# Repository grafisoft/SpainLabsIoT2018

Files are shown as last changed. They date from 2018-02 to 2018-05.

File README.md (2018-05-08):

Banner

Banner

# SpainLabsIoT2018
Hardware&Firmware creado para el mini curso IoT basado en ESP8266

En este repositorio se pretende subir todos los archivos correspondientes al hardware y firmware creados para el 
curso de IoT SpainLabsIoT2018. Podemos acceder a los contenidos desde el enlace: https://www.spainlabs.com/foros/tema-SpainLabs-con-el-IoT-para-tod-s

El hardware lo podemos ver mas en detalle en: https://www.spainlabs.com/foros/tema-SpainLabsIoT2018-Caso-real-Nodos-ESP8266

El hardware esta basado en la integración del módulo de comunicaciones wifi ESP8266 en sus especificaciones 07/12/12E.

El proyecto del firmware que se ofrece esta escrito usando el IDE de Atom+ Proyecto PlatformIO: https://platformio.org/

Este proyecto forma parte de la comunidad maker spainlabs.com y mas concretamente al usuario Grafisoft.

Podeis hacer uso de todo el contenido sin restricciones siempre y cuando se indique que pertenece a Grafisoft de spainlabs.com

Características:

- Placa desarrollada para ESP8266-07/12/12E.
-Dimensiones: 78mm x 41mm.
- Módulo ESP extraible o posibilidad de soldar directamente sobre la PCB.
- Etapa de carga para las baterías Lipo. Ya sea mediante panel solar (6V-1W) o mediante una conexión de 5V externa.
- Todos los pines del ESP son accesibles. También lo son los de alimentación (tanto Vbat como Vext).
- Programación del ESP desde la propia placa mediante un conversión USB-Serie (este conversor debe ser un modelo que tenga ciertos pines accesibles).
- Bajo consumo en DeepSleep: <50uA.
- Conexión de una batería mediante conector JST o compatible con un holder para baterías de 1 o 2 celdas tipo 18650.
- Botón de reset.
- Nivel de batería: Podremos consultar el nivel de nuestras baterías para conocer su estado.
- Modular: Esto es, no es necesario tener soldadas todas las etapas para su funcionamiento. De cara a desplegar una red, no tenemos porque soldar todos los componentes para tener un nodo operativo. Por lo que tenemos un cierto ahorro en el momento de desplegar nodos.
- Se dispone de zócalos para poder pinchar una placa encima de forma que en ella podamos integrar la electrónica necesaria para añadir mas sensores.
- Se ha dejado huella para zócalo 2x2 y disponer unicamente acceso a I2C y alimentación 3v3.
- Su coste en componentes ronda los 6€ sin incluir el módulo ESP ni batería(s). Es un coste bastante razonable.

Desarrollo de una shield para conectar sensores: https://github.com/grafisoft/Smart-Sensors-Shield

-------------------------------------------------

ESp8266 IoT Board for SpainLabsIoT2018 course is based on ESP8266 NodeMCU. Some changes are do and new version is created. We can use the board as if we were using NodeMCU or any ESP8266 module.

Features:

- Board developed for ESP8266-07/12/12E version modules.
- Dimensions: 78mm x 41mm.
- Designed to use non-fixed modules or you can soldier it.
- Include battery Lipo charger. We can use a solar panel (6V-1W) or external power-dc 5v.
- All ESP8266 module pins are accessible. Power pins accessible too (Vbat and Vext).
- ESP8266 can be programmed using external USB-Serial: https://www.ebay.es/itm/USB-2-0-to-TTL-UART-6PIN-CP2102-Module-Serial-Converter-T1/252583963023?rmvSB=true 
- Low power DeepSleep current: 50uA. *Note: We need extract resistor betwen leds components.
- Battery connector is JST type or we can use a battery holder (1 or 2 cells). Battery type is 18650.
- Reset button.
- Battery level: ADC of ESP module is used to measure battery level.
- It is not necessary to weld all the components. Board can work with parcial smd components. We can get low cost when we need to deploy some nodes and weld necessary components only. 
- Board provide some connectors to add personal shields and increase board features or integrate new sensors.
- Board include footprint for I2C connector. Shape is 2x2.
- Board costs are over 6€. Not included ESP module or battery.

I am developing a shield for sensors: https://github.com/grafisoft/Smart-Sensors-Shield

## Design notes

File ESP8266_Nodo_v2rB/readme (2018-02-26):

Gerbers para enviar a fabricar el modelo de placa.

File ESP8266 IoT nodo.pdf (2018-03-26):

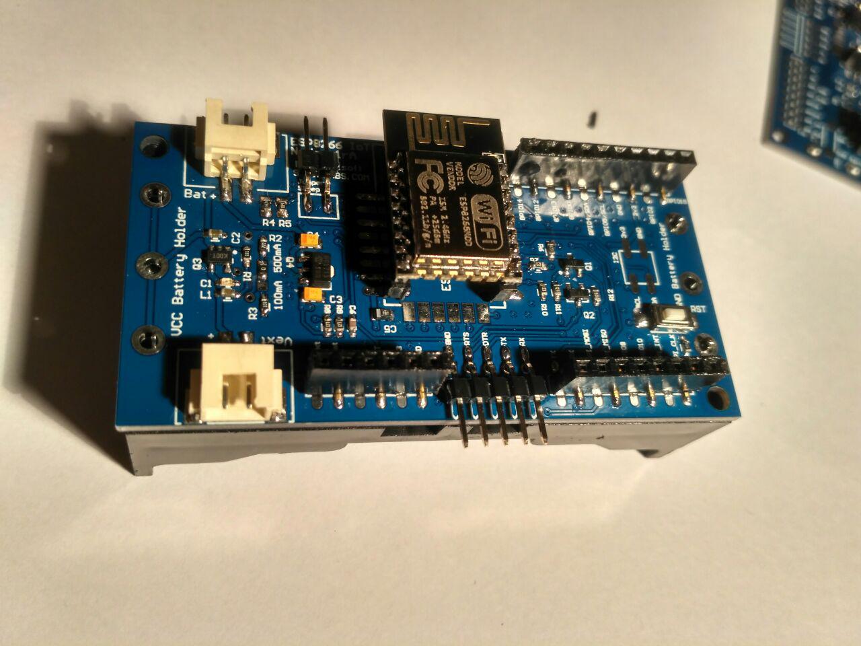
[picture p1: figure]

# ESP8266 IoT nodo

Hardware para el curso SpainLabsIoT2018. V1rA/v2Ra. By Grafisoft – www.spainlabs.com
Version documentación: rev3.

## Introducción

En esta documentación se va a abordar lo relacionado al hardware que se ha diseñado para aplicar los diferentes puntos vistos en el curso SpainLabsIoT2018.

## Hardware

Para disponer de una plataforma hardware sobre la que aplicar lo que se ha ido publicando, se ha diseñado el siguiente nodo. Se ha basado el diseño en NodeMCU Lolin, quedándonos con lo que necesitábamos y añadiendo alguna cosilla más. El objetivo era disponer de un hardware económico sin perder de vista el uso que iba a tener.
El hardware es Open Source. Se dispone de los Gerbers para poder fabricar más PCBs.
El proyecto está desarrollado en la comunidad SpainLabs, concretamente en: https://www.spainlabs.com/foros/tema-SpainLabsIoT2018-Caso-real-Nodos-ESP8266 GitHub: https://github.com/grafisoft/SpainLabsIoT2018
Características

Alimentación batería: LiPo 3,7V (1S).
Alimentación Max en el conector de batería: 5V.
Alimentación desde el conector Vext: 7V. Vext mínima recomendada 5v.
- Panel solar recomendado: 6-7v 2-3W.
- Carga de batería con dos opciones, a 100mA y 450mA (seleccionable mediante una resistencia).
Alimentación del módulo ESP8266 a 3v3 y 200mA de Imax.
Consumo: 150mA en transmisión Wifi.
- DeepSleep: sobre 50uA.
Botón de reset.
Jumper para habilitar/deshabilitar Deepsleep. En alguna de las versiones del ESP, este jumper en el momento de programar no puede estar colocado.
Compatible con ESP8266 especificaciones 07/12/12E
- Posibilidad de tener todos los pines accesibles.
- Zócalos para programar y posibilidad de poder hacer shields para integrar nuevos sensores.
- El módulo ESP8266 puede ser soldado directamente sobre la PCB o pueden añadirse zócalos de 2.00mm para poder extraerlo.
Conectores para batería y panel solar con conector JST. Posibilidad de añadir holder para las baterías tipo 18650. 1 celda o batería o 2 celdas o baterías (en paralelo).
Hardware escalable. No es necesario soldar todos los componentes para su correcto funcionamiento.

Opcionales:
- Etapa de carga.
- Etapa para la programación (se dispone de una etapa de transistores para poder programar el modulo ESP. No es necesaria para tener comunicación UART y/o el funcionamiento normal).
Puerto I2C duplicado. Se han sacado los pines necesarios de I2C para poder conectar directamente un sensor (3v3, GND, SDA, SCL).
Control del nivel de batería. El puerto ADC del módulo ESP se ha usado para medir la tensión de la batería. Existen ICs ADC por I2C en caso de necesitarlos.
Dimensiones: 79mm x 41mm.
Nota1: Es necesario alimentar la PCB para realizar la programación del módulo ESP. No se toma la alimentación del módulo USB-Serie por no ser suficiente.

## Esquema de conexiones

A continuación vamos a ver el pinout de la PCB. Hemos respetado el nombre de cada pin respecto al nombre que tiene en el módulo ESP8266, por tanto tiene una equivalencia directa.

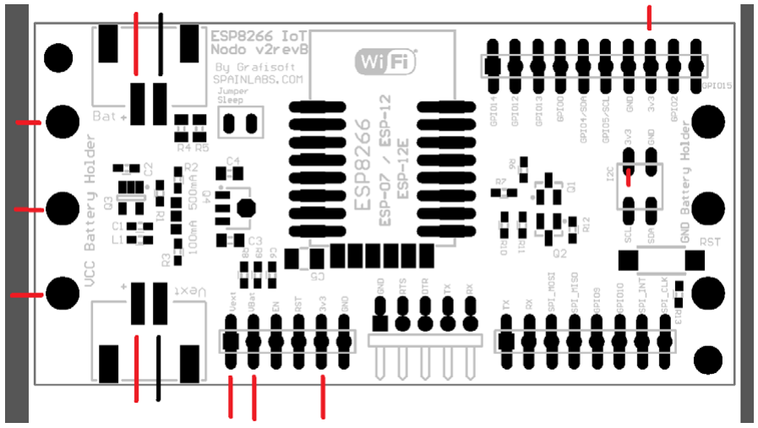
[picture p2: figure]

Se han marcado en rojo todas las alimentaciones positivas. En negro las negativas. Todos los pines GND son las conexiones negativas.
Los pines con serigrafía 3v3 corresponden a que en ese pin disponemos de alimentación 3v3. No es para meter de forma externa una alimentación 3v3.
Los pines Vext y Vbat son los mismos que se dispone en los conectores JST. Se han duplicado por si se quieren controlar desde una shield que se pinche encima. Estos pines sí que son para alimentar la PCB.

Si nos vamos al módulo ESP8266 más completo, este sería la especificación 12E. Esta versión tiene todos sus pines accesibles. Las versiones 07 y 12 tienen los mismos pines a excepción de los pines de la parte superior.

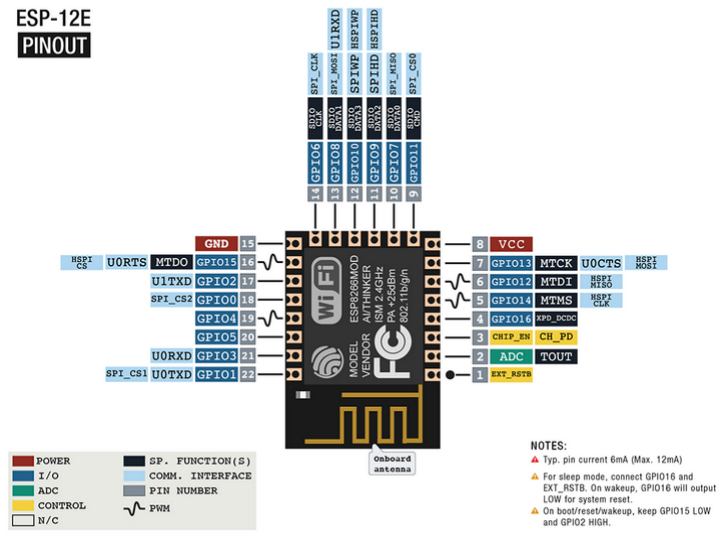
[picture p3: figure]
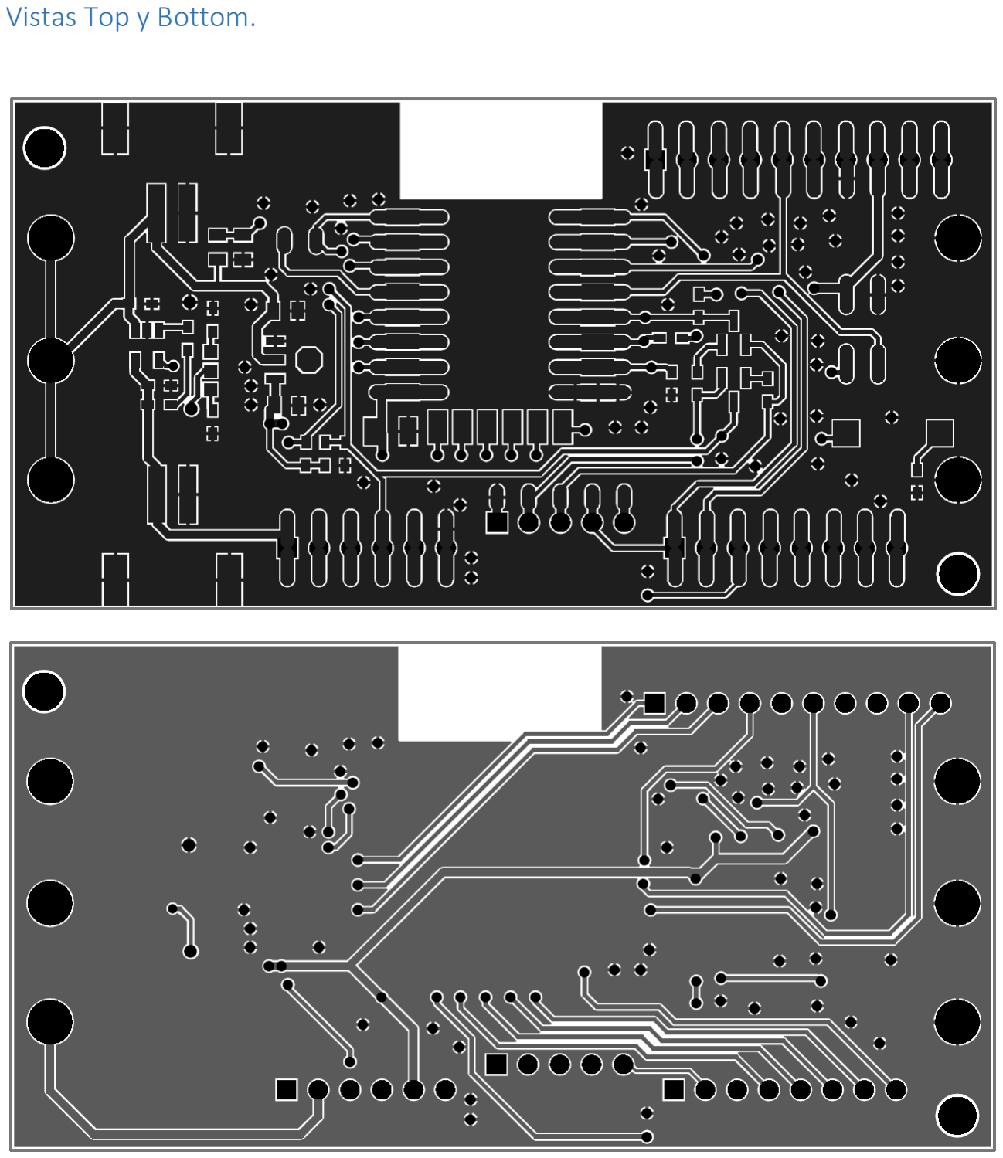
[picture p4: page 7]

Vistas Top y Bottom.

## Conexionado para programación mediante USB-Serie

Para realizar la programación del módulo ESP8266 en cualquiera de las 3 versiones que es compatible la PCB, podremos usar un conversor USB-Serie. Lo único que debemos tener en cuenta es que tenga accesibles ciertos pines el conversor.
Vamos a necesitar los siguientes pines para poder hacer la programación: GND, TXD, RXD, DTR, RTS.
Nota: Recordar que en el momento de conectar los pines RX y TX, debemos cruzarlos. Es decir, el RX del conversor USB-Serie tendrá que ir al TX de la PCB y lo mismo con el RX del conversor, que tendrá que ir al TX de la PCB.
Añado una imagen para que quede más claro con los cables de diferente color.

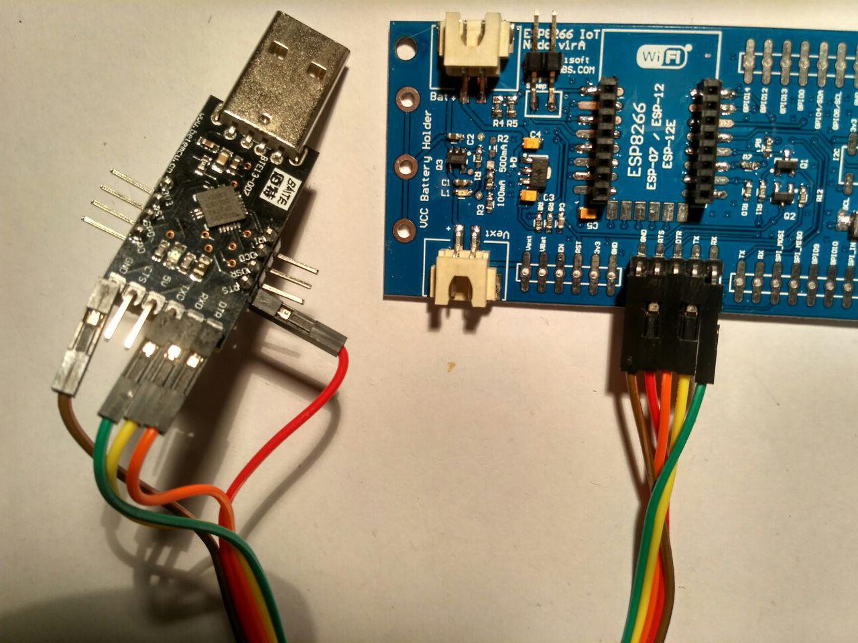
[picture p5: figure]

## Ajustar corriente para la carga de la(s) batería(s)

En la PCB disponemos de un sitio para elegir que corriente de carga queremos usar. Esta elección es manual, mediante un puente donde con una resistencia de 0 ohm 0603/0805 o un puente de estaño, elegiremos que resistencia pre configurada queremos usar para establecer la corriente de carga en la batería.

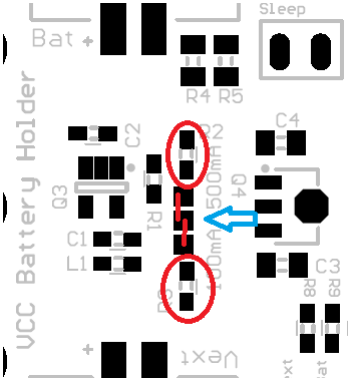
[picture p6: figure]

Las posiciones de las resistencias R2 y R3 son las que pre configuran 2 valores distintos de carga. Siendo R2 el que con una resistencia de 2k2 ohm configura casi el máximo de corriente que puede cargar el IC encargado, correspondiente a unos 450mA. Mientras tanto, para un valor de 100mA usaremos un valor de 10k ohm. Si se quieren valores intermedios, es una simple regla de tres. Por ejemplo, para una carga de 250mA tendríamos que usar una resistencia de aproximadamente 5k6 ohmios.
En la imagen adjunta, se pueden apreciar 3 cuadros, estos se usan para seleccionar que valor de resistencia usar. Uniendo el pad centra con uno de los extremos, elegiremos una configuración u otra.

Flashear módulo ESP8266 sin estar conectado a la placa.

En alguna ocasión, puede que carguemos algún código que nos deje el modulo en un estado que no es posible volver a cargar código. Para poder recuperarlo, tenemos que conectarlo de la siguiente forma al conversor usb-serie y realizar nuevamente la operación de carga de código:

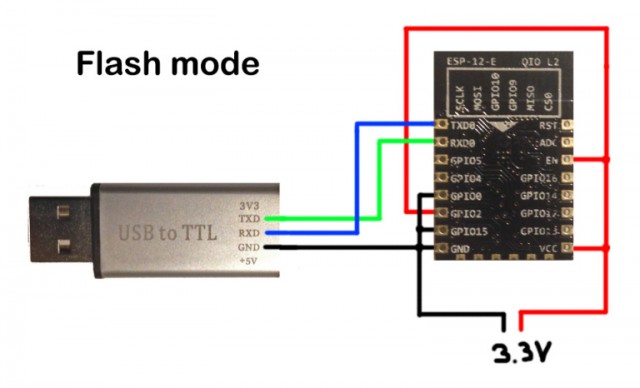
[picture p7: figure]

## Changelog

- Versión 1 y 2: Creación.
- Versión 3 - 26/3/2018 – Apartado “Flashear módulo ESP8266 sin estar conectado a la placa.

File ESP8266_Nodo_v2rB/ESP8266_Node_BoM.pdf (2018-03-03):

Nombre PCB: ESP8266IoT Nodo v1rA/v2rA ‐ 3/3/18
Componente | Ref.PCB | Descripcion | Enlace
PCB | | PCB | Disponibles los gerber para mandarlos a fabricar donde se prefiera
Conector smd 2P | Bat, Vext | Conector smd 2P. bBteria y conexión externa/solar | https://www.aliexpress.com/item/20PCS‐YT2010‐XH‐2‐54‐mm‐Spacing‐Connector‐2P‐3P‐4P‐5P‐6P‐7P‐8P‐Horizontal/32820204844.html?spm=a2g0s.9042311.0.0.WUy88
Zocalo smd hembra 2mm | ‐ | Zocalo para el ESP8266 | https://es.aliexpress.com/item/20‐UNIDS‐2‐54mm‐Jefe‐Femenino‐Del‐Pin‐Conector‐1x40‐P‐Sola‐Fila‐SMT‐SMD‐Longitud/32833981842.html?spm=a2g0s.9042311.0.0.3G
Battery holder 2 celdas | ‐ | Porta baterias de 2 unidades (Opcional). 1 celda compatible | https://www.ebay.es/itm/5‐x‐2‐18650‐Cell‐Battery‐Holder‐Case‐Box‐Leads‐Pins‐PCB‐Board‐Mount‐Plastic/401493563806?ssPageName=STRK%3AMEBIDX%3AIT&_trksid=
ESP8266 | ESP8266 | Versiones compatibles: 07/12/12E
Pines macho 2.00mm | ‐ | Pines para soldar al modulo ESP8266
Pines macho 2,54mm smd horizontal | ‐ | Pines para Jumper Sleep y puerto grabacion/uart | https://es.aliexpress.com/item/10pcs‐2‐54‐mm‐2‐3‐4‐5‐6‐7‐8‐9‐10‐12‐14‐15/32821748577.html?spm=a2g0s.9042311.0.0.3GBY71
Pines macho/hembra 2,54mm smd | ‐ | Pines para los puertos de expansión
mcp73831t‐2aci | Q3 | Cargador bateria | https://www.ebay.es/itm/10PCS‐MCP73831T‐2ACI‐OT‐SOT23‐5‐Charge‐Management‐Controller‐R3/221926855267?ssPageName=STRK%3AMEBIDX%3AIT&_trksid=p2057
MCP1700T‐330 | Q4 | Puede usarse el MCP1702T‐330
12k 0603 smd Resistencia | R6,R7,R8,R9,R10,R11,R12 | Resistencia
10k 0603 smd Resistencia | R3 | Resistencia
100k 0603 smd Resistencia | R5 | Resistencia
470k 0603 smd Resistencia | R4 | Resistencia
330 0603 smd Resistencia | R1 | Resistencia
2k2 0603 smd Resistencia | R2 | Resistencia
470 0603 smd Resistencia | R13 | Resistencia
0 ohm 0603 smd Resistencia | Puente | Para seleccionar corriente de carga bateria
4,7uF 0603 smd condensador ceramico | C1,C2 | Condensador
470pF 0603 smd condensador ceramico | C6 | Condensador
1uF 0805 smd condensador tantalio | C3,C4 | Puede ser condensador ceramico
47uF 0805 smd condensador tantalio | C5 | Se puede usar uno de 100uF de tantalio
Led Rojo smd 0603 | L1 | Led
BC847 sot‐23 | Q1,Q2 | Se puede usar el transistor J3Y sot‐23
Pulsador smd 3x6x2,5 | RST | Pulsador para "reset"

Proyecto SpainLbasIoT2018 ‐ Hardware Nodo ESP8266 BoM

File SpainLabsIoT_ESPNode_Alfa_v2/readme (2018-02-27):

Firmware para el modulo ESP8266.
El proyecto esta creado bajo Atom+PlatformIO. Tiene un sistema propio para gestionar las librerias. Es necesario "instalar "las 
librerias siguientes:
    Adafruit BME280 Library
    Adafruit Unified Sensor
    PubSubClient
    
Al bajar todo el proyecto y cargarlo, sera necesario disponer previamente de las librerias. 
En caso de no encontrarlas, os dejo las librerias necesarias en la carpeta del proyecto "/lib". En caso de que al compilar 
os genere algun error, las librerias las tendreis que mover a la carpeta dentro del proyecto ".piolibdeps".

Las librerias no han sido modificadas, por lo que podeis descargarlas desde la interfaz del Atom+PlatforIO.

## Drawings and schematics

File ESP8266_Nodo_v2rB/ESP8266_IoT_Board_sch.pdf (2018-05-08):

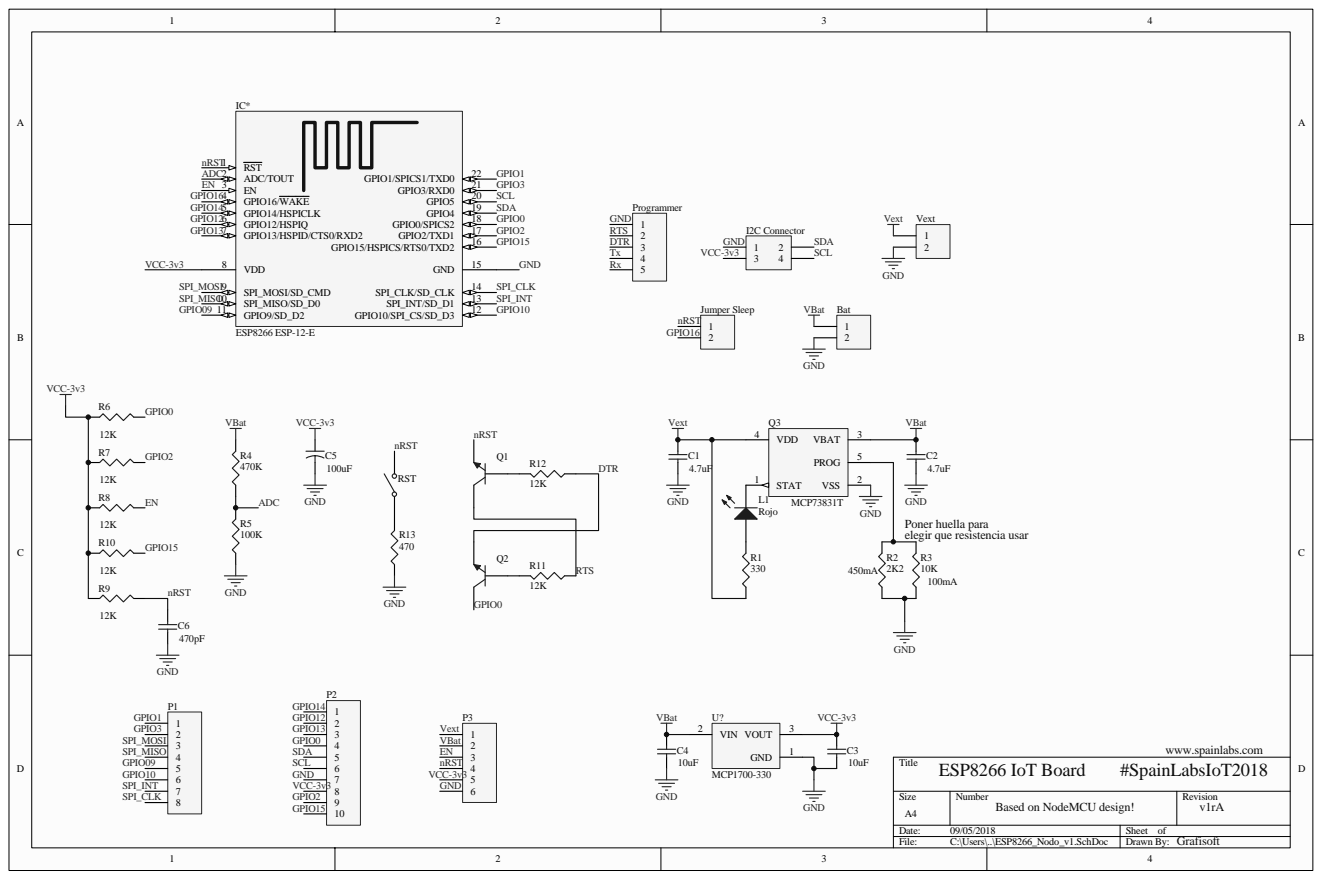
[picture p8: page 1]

GND
Poner huella para
elegir que resistencia usar

Date: 09/05/2018 | Sheet of
File: C:\Users\..\ESP8266_Nodo_v1.SchDoc | Drawn By: Grafisoft

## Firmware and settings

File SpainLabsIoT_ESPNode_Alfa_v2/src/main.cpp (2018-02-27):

/*
 CURSO BASICO IOT DE LA COMUNIDAD SPAINLABS.COM
 Firmware basico para el hardware: ESP8266 IoT Nodo v1rA.
 Compatible con las versiones del modulo ESP8266: esp-07/12/12E.
 Enlace: https://www.spainlabs.com/foros/tema-SpainLabsIoT2018-Caso-real-Nodos-ESP8266
 Firmware para el hardware desarrollado en el curso SpainLabsIoT2018.
 Enlace: https://www.spainlabs.com/foros/tema-SpainLabs-con-el-IoT-para-tod-s

 Este software realiza de forma esquematica lo siguiente:
 Lee el sensor BME280 y nivel de bateria -> Envia las tramas MQTT -> Duerme.
 El sensor BME280 nos da parametros de tipo temperatura, humedad y presion.

 Se usa el protocolo MQTT que crea topics en funcion del nombre del nodo y el
 valor que vamos a publicar del sensor o nivel de bateria. Los topics son
 similares a: "sensor/NodeName/temp".

 Diseño: Grafisoft.
 Fecha: 25/2/2018.
 Version: 2 revA.
*/


#include <Arduino.h>
//Todas las funciones e includes de librerias estan en funciones.h
#include "funciones.h"
float battery;
//----------------------- CONFIG PARAMETERS------------------------
//Con este parametro se construye todos los topics para el protocolo MQTT.
// Nombre del nodo.
String NodeName = "Testing";
String TopicMQTT; //Variable para construir el Topic de MQTT.
//El tiempo de sueño se especifica en el fichero funciones.h (sleeptime).
//-----------------------------------------------------------------

void setup() {

  Serial.begin(115200); //Velocidad del UART.
  setup_wifi();
  //Configuracion conexion a MQTT.
  client.setServer(mqtt_server, 1883);
  client.setCallback(callback);

  Serial.println(F("SpainLabsIoT2018 Firm ESP8266 esp-07/12/12E"));
  Serial.println(F("Firmware version: v2 revA"));

  //Inicializamos el sensor bme280.
  bool status;
  
  // I2C Addres configurada en 0x76. Hay sensores(plaquitas con el sensor integrado)
  //que estan en 0x77. Desde bme.begin(I2C_ADDRESS) se puede cambiar.
  status = bme.begin(0x76);
  delay(1000); // let sensor boot up
  if (!status) {
      Serial.println("Could not find a valid BME280 sensor, check wiring!");
      while (1);
  }

  Serial.println("-- Default Test --");
  //Lectura del nivel de bateria.
  Serial.print("Battery Status: ");
  //El ADC del ESP8266 solo lee hasta 1V.
  //Se usa un divisor resistivo con Rs de 470K-100K.
  //Valores altos de las Rs para tener un consumo minimo.
  battery = (analogRead(0)/1024.0)*5.55;
  Serial.print(battery);
  Serial.println(" V ");
  Serial.println();
}

void loop() {

  //Lectura del sensor y envio de datos al monitor serie.
  leerbme();

  //Conexión con el broker MQTT.
  if (!client.connected()) {
    reconnect();
  }
  client.loop();

  long now = millis();
  if (now - lastMsg > 2000) {
    lastMsg = now;
    ++value;
    snprintf (msg, 75, "Prueba trama #%ld", value);
    Serial.print("Publish message: ");
    Serial.println(msg);

    //Bloque para el envio del valor temperatura.
    char valTemperature[5];
    dtostrf(bme.readTemperature(), 3, 1, valTemperature);
    String payload; //Variable para contener la info de la trama que se envia.
    //Creamos la trama. Sera del estilo: "sensors/NodeName/temp"
    TopicMQTT = "sensors/" + NodeName + "/temp";
    //Creamos el mensaje. Sera del estilo: "NodeName temperature=";
    payload = ""; //Limpiamos la variable.
    payload += NodeName;
    payload += " temperature=";
    payload += valTemperature;
    //Enviamos la trama via MQTT.
    client.publish((char*) TopicMQTT.c_str(), (char*) payload.c_str());
    delay(3000);

    //Bloque para el envio del valor humedad.
    char valHumidity[5];
    dtostrf(bme.readHumidity(), 3, 1, valHumidity);
    //Creamos la trama. Sera del estilo: "sensors/NodeName/humidity"
    TopicMQTT = "sensors/" + NodeName + "/humidity";
    //Creamos el mensaje. Sera del estilo: "NodeName humidity=";
    payload = ""; //Limpiamos la variable.
    payload += NodeName;
    payload += " Humidity=";
    payload += valHumidity;
    //Enviamos la trama via MQTT.
    client.publish((char*) TopicMQTT.c_str(), (char*) payload.c_str());
    delay(3000);

    //Bloque para el envio del valor Bateria.
    char valBattery[5];
    dtostrf(battery, 3, 1, valBattery);
    //Creamos la trama. Sera del estilo: "sensors/NodeName/bat"
    TopicMQTT = "sensors/" + NodeName + "/bat";
    //Creamos el mensaje. Sera del estilo: "NodeName Battery=";
    payload = ""; //Limpiamos la variable.
    payload += NodeName;
    payload += " Battery=";
    payload += valBattery;
    //Enviamos la trama via MQTT.
    client.publish((char*) TopicMQTT.c_str(), (char*) payload.c_str());
    delay(3000);

    //Mensaje para indicar que la trama se ha enviado.
    Serial.println("-- Tramas enviadas! --");
    //En la version ESP12 y ESP12E existe un bug. Hay que desconectar el Wifi
    //para que despues de despertar, no se quede bloqueado el nodo.
    WiFi.disconnect();
  }
  delay(1000);
  // Tiempo de deepSleep especificado en 'sleeptime'.
  ESP.deepSleep(sleeptime, WAKE_RF_DEFAULT);
}

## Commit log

2018-02-26 Subidos los gerbers para fabricación.
    Subidos los gerbers para fabricación - versión 2 rev B
    [ESP8266_Nodo_v2revB.GBL, ESP8266_Nodo_v2revB.GBO, ESP8266_Nodo_v2revB.GBS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]
2018-02-27 Firmware ESP8266 v2
    Primera publicación del firm para el ESP8266 v2.
2018-03-03 Añadido BoM versión hardware v1rA/v2rB
    BoM versión hardware v1rA/v2rB
2018-03-13 Actualización documentacion
    Añadida información sobre como conectar el conversor USB-Serie y configurar diferentes niveles de carga para la bateria.
2018-05-08 Esquematico ESP8266 IoT Board v1/v2
    Esquemático de la placa.
